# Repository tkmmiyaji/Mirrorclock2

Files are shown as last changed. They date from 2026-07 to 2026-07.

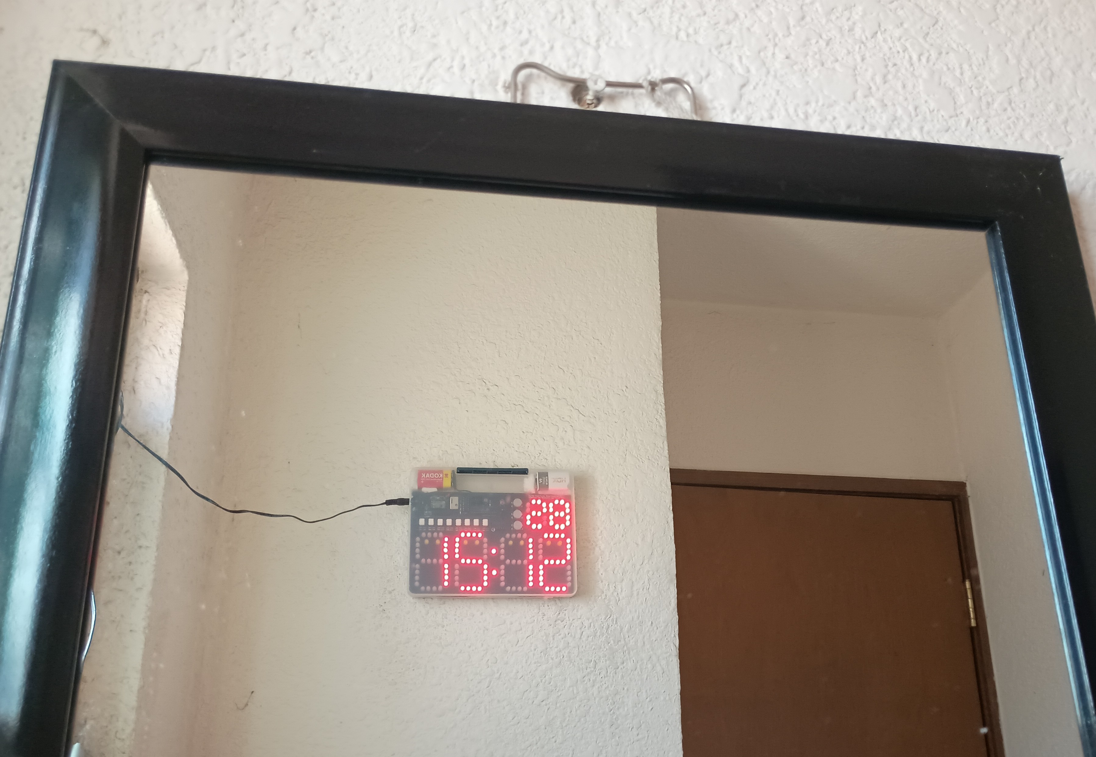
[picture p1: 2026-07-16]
Gallery/Through_the_Looking-Glass.jpg

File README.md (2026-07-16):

# Mirrorclock2 --- Through the Looking Glass and How the Digital Clock Looks
# 鏡の国のデジタル時計  Ver. 2.2 b 

### by Homebrew and Electronics Lab Cosmic Web, 16 Jul, 2026

## Summary
This repository contains the hardware designs (KiCAD) and the software (AVR assembly language). The hardware design and software are distributed with the Beerware license. See LICENSE.md  

## Hardware

The KiCAD Ver. 10 project files (incl.  kicad_pro, kicad_pcb, and kicad_sch files are included with necessary ./KiCAD.

* AVR: The 28-dip pachage of the Atmega48,88,168,328 and variants should work. 
* The resistor footprints on the PCB accept either THT (3 DIP pitches/7.62mm between holes) or SMD (1206) components. The LED footprints accept 3mm, 5mm diameter ones that have one DIP pitch (2.54mm) between leads. You may be able to place SMD LEDs if you dare.
* Place the tilt switch diagonally, so that the display is stably in the normal mode (see below) when it is placed on a level surface. See ./Gallery/Tilt_Switch_small.jpg.

### Hard-to-find components

* The temperature-compensated Crytsal Module Kyocera KTXO-18 (12.8MHz) or Mercury VCTCXO VM39S5G is used. The latter can be purchased at Akizuki Denshi Tsuusho in Akihabara, Tokyo (https://akizukidenshi.com/catalog/g/g107275/) (availbale as of July, 2026). There may be easier-to find equivalent SMD parts, but to use these a modification in the PCB footprint is required.  

## Software AVRClock2

This software is written in the assmbly language and can be compiled with avra (https://github.com/Ro5bert/avra) and uploaded to the chip using avrdude (https://github.com/avrdudes/avrdude/), both included in the standard repositories of many Linux distros.

### How to Compile/Install (Linux)
* Install avrdude and avra to your system.
* Connect an ISP programmer to the ISP header (6-pin) on board. Watch the orientation. Match the ISP connector bump to that of the PCB drawing.
* Go to directory: ./AVRA
* Open Makefile in your editor and edit the lines with "MCU_TARGET =" and "PROGRAMMER =" to your chip and programmer respectively. Check the port where the programmer is connected and adjust the PORT=/dev/ttyUSB0 line if needed.
* Also the LED brightness auto-adjustment parameters can be set by editing "FA_LIM =" and "BR_LIM =" lines. See Makefile comments for more explanations. 
* From the shell: <br>
SHELL>make                # This compiles the program. <br>
SHELL>make install        # This installs (uploads) the binary to the chip. <br>

## Usage Instructions 
* Connect an external 12V power source.
* It is highly recommended to connect a 9V rectangular battery (called 006P in Japan) for time backup.
* When the unit turns on or reset with the RST button, the clock displays 00:00 00. The clock starts running.
* __Time Adjustment:__ There are three buttons aligned vertically. With a long (~2 sec) push of the central button (MODE), the system enters the hour adjustment mode. Dots in the hour zone blink. You can adjust hours by pushing the upper (ADJ_FWD) and/or lower (ADJ_BWD) buttons. One more pressing of the central button leads to the minute adjustment mode. Dots in the minute zone blink. Use the ADJ_FWD and/or ADJ_BWD buttons to adjust the minute. Note that a long push **will not** make the forward/backward move fast. Whenever the minute is changed, the second zone is reset to zero. When you want to adjust the clock to a second level, push the ADJ_FWD/ADJ_BWD button at the exact moment the reference clock ticks a zero second.
* One more push of the MODE will return the clock to the normal mode.
* __LED Check:__ In the normal mode, pressing the upper button will turn on all the LEDs.
* LED brightness changes responding to the ambient brightness. A press of the lower button shows some calibration and brightness information. There is a trimpot for limited adjustments of the ambient-to-LED brightness relation. Wider range of adjustment is possible in the software (See above).
* __Normal Mode:__ When the clock is right-side up or on a level surface (i.e. the HH:MM display is above the circuts), it displays the clock normally.
* __Mirror Mode: Turn the clock upside down and look through a mirror!__ The roles of ADJ_FWD and ADJ_BWD buttons are also exchanged in the time adjustment.

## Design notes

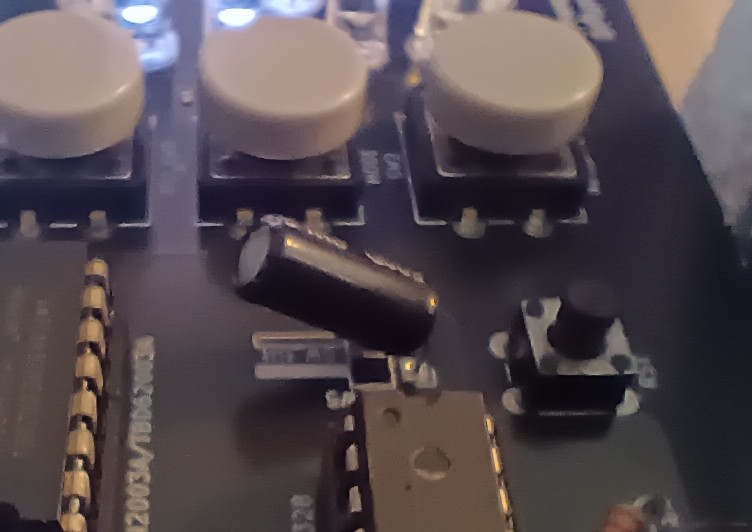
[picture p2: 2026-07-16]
Gallery/Tilt_Switch_small.jpg

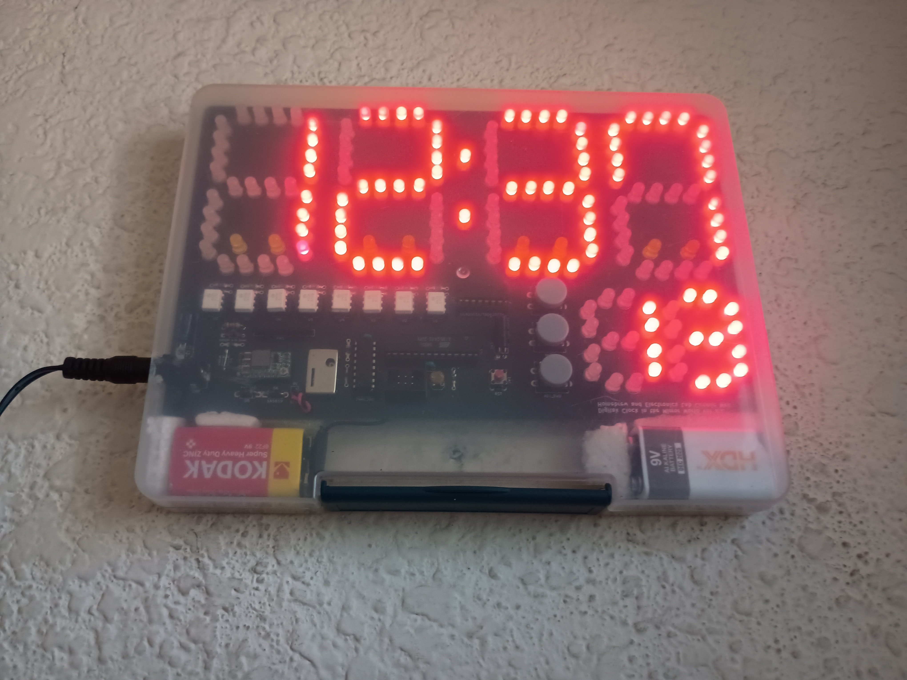
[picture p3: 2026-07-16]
Gallery/NormalMode.jpg

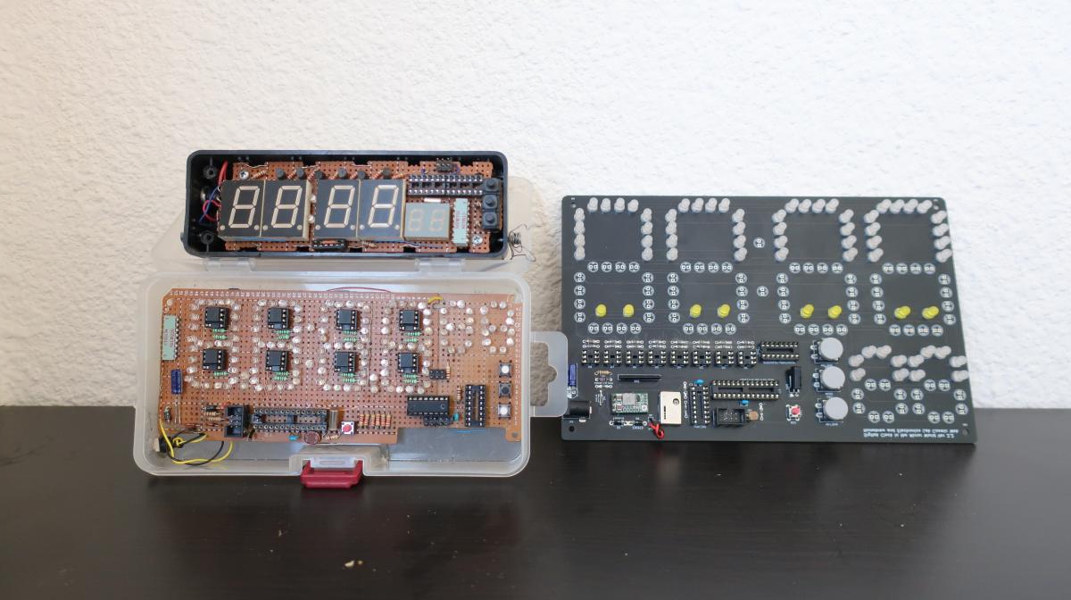
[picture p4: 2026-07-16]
Gallery/MirrorClock_Generations_small.jpg

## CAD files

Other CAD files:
AVRA/AVRClock2.obj

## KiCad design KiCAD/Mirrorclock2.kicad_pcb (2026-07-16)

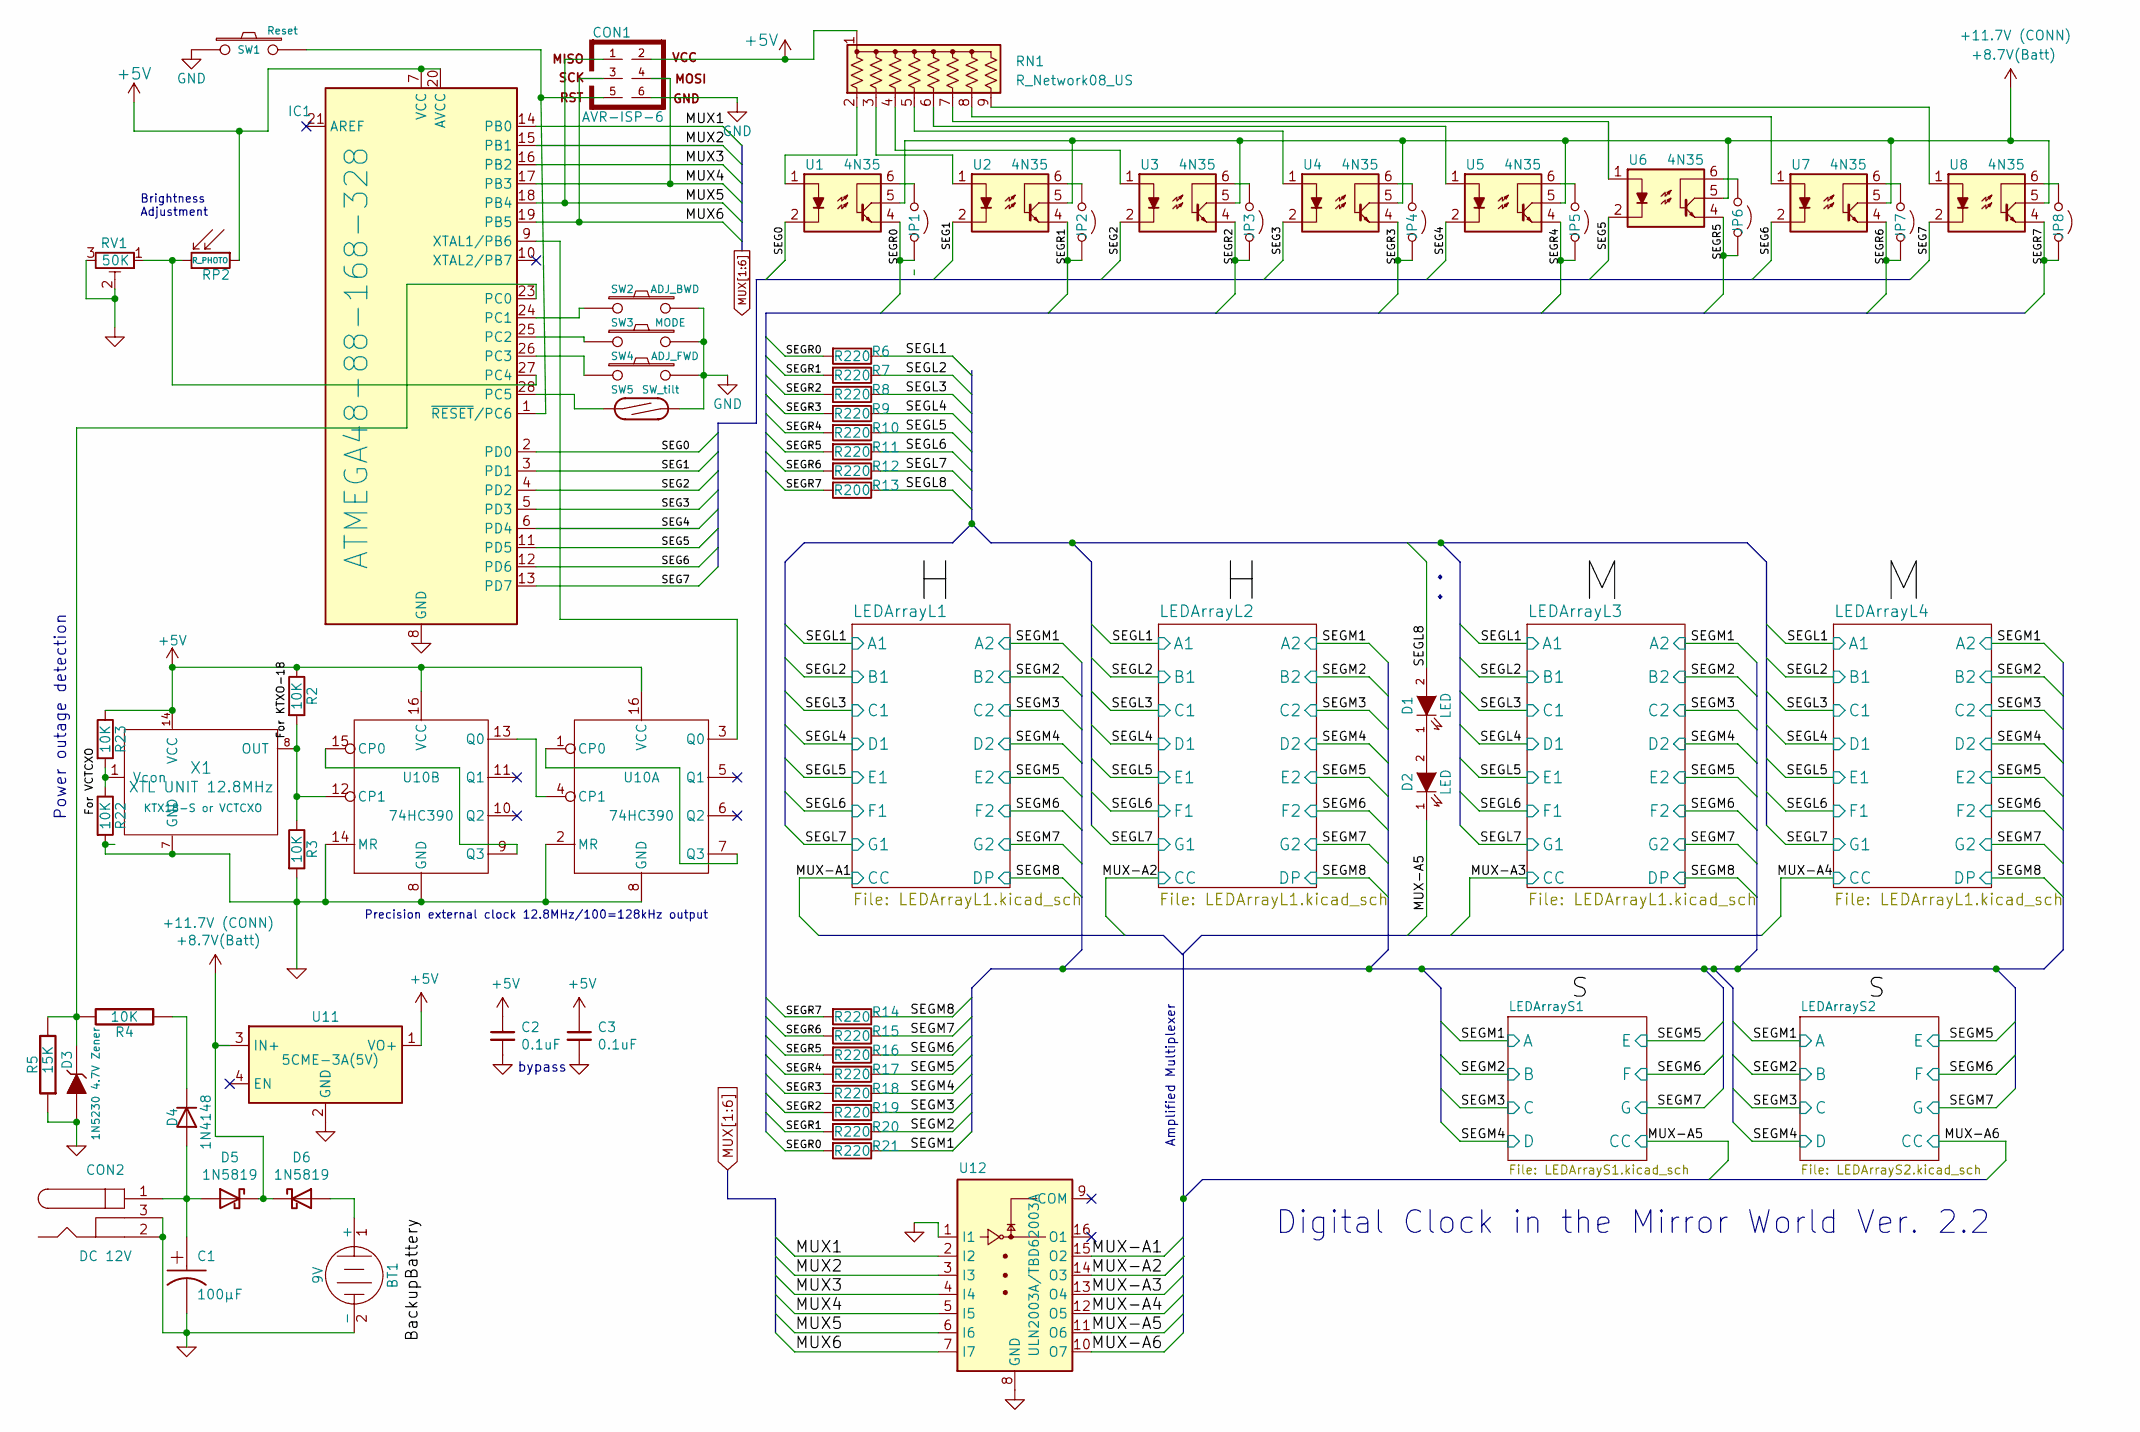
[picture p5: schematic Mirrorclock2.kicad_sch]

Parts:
BT1: 9V; PinHeader_1x02_P2.54mm_Vertical
C1: 100μF; CP_Radial_D6.3mm_P2.50mm
C2, C3: 0.1uF; C_Disc_D3.4mm_W2.1mm_P2.50mm
CON1: AVR-ISP-6; AVRISP-6P
CON2: DC 12V; BarrelJack_Horizontal
D1, D2: LED; LED_MULTI
D3: 1N5230 4.7V Zener; D_DO-34_SOD68_P7.62mm_Horizontal
D4: 1N4148; D_DO-35_SOD27_P7.62mm_Horizontal
D5, D6: 1N5819; D_DO-41_SOD81_P7.62mm_Horizontal
IC1: ATMEGA48-88-168-328; DIP-28_W7.62mm
JP1, JP2, JP3, JP4, JP5, JP6, JP7, JP8: Jumper_2_Open; SolderJumper-2_P1.3mm_Open_RoundedPad1.0x1.5mm
R2, R3, R4, R22, R23: 10K; R_THT_SMD1206
R5: 15K; R_THT_SMD1206
R6, R7, R8, R9, R10, R11, R12, R14, R15, R16, R17, R18, R19, R20, R21: R220; R_THT_SMD1206
R13: R200; R_THT_SMD1206
RN1: R_Network08_US; R_Array_SIP9
RP2: R_PHOTO; R_LDR_5.1x4.3mm_P3.4mm_Vertical
RV1: 50K; Potentiometer_Runtron_RM-065_Vertical
SW1: Reset; SW_PUSH_6mm
SW2: ADJ_BWD; SW_PUSH-12mm_Wuerth-430476085716
SW3: MODE; SW_PUSH-12mm_Wuerth-430476085716
SW4: ADJ_FWD; SW_PUSH-12mm_Wuerth-430476085716
SW5: SW_tilt; Sw_tilt_holes
U1, U2, U3, U4, U5, U6, U7, U8: 4N35; DIP-6_W7.62mm
U10: 74HC390; DIP-16_W7.62mm
U11: 5CME-3A(5V); DCDC-Module-Drok
U12: ULN2003A/TBD62003A; DIP-16_W7.62mm
X1: XTL UNIT 12.8MHz; Crystal_M39S_KTXO18; Part KTX18-S or VCTCXO

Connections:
+5V: C2.1, C3.1, CON1.2, IC1.7 (VCC), IC1.20 (AVCC), R2.1, R23.1, RN1.1 (common), RP2.1, U10.16 (VCC), U11.1 (VO+), X1.14 (VCC)
+12V: D5.1 (K), D6.1 (K), U1.5, U2.5, U3.5, U4.5, U5.5, U6.5, U7.5, U8.5, U11.3 (IN+)
/MUX1: IC1.14 (PB0), U12.2 (I2)
/MUX2: IC1.15 (PB1), U12.3 (I3)
/MUX3: IC1.16 (PB2), U12.4 (I4)
/MUX4: CON1.4, IC1.17 (PB3), U12.5 (I5)
/MUX5: CON1.1, IC1.18 (PB4), U12.6 (I6)
/MUX6: CON1.3, IC1.19 (PB5), U12.7 (I7)
/MUX-A1: U12.15 (O2); also elsewhere on the board
/MUX-A2: U12.14 (O3); also elsewhere on the board
/MUX-A3: U12.13 (O4); also elsewhere on the board
/MUX-A4: U12.12 (O5); also elsewhere on the board
/MUX-A5: D2.1 (K), U12.11 (O6); also elsewhere on the board
/MUX-A6: U12.10 (O7); also elsewhere on the board
/SEG0: IC1.2 (PD0), U1.2
/SEG1: IC1.3 (PD1), U2.2
/SEG2: IC1.4 (PD2), U3.2
/SEG3: IC1.5 (PD3), U4.2
/SEG4: IC1.6 (PD4), U5.2
/SEG5: IC1.11 (PD5), U6.2
/SEG6: IC1.12 (PD6), U7.2
/SEG7: IC1.13 (PD7), U8.2
/SEGL1: R6.1; also elsewhere on the board
/SEGL2: R7.1; also elsewhere on the board
/SEGL3: R8.1; also elsewhere on the board
/SEGL4: R9.1; also elsewhere on the board
/SEGL5: R10.1; also elsewhere on the board
/SEGL6: R11.1; also elsewhere on the board
/SEGL7: R12.1; also elsewhere on the board
/SEGL8: D1.2 (A), R13.1
/SEGM1: R21.1; also elsewhere on the board
/SEGM2: R20.1; also elsewhere on the board
/SEGM3: R19.1; also elsewhere on the board
/SEGM4: R18.1; also elsewhere on the board
/SEGM5: R17.1; also elsewhere on the board
/SEGM6: R16.1; also elsewhere on the board
/SEGM7: R15.1; also elsewhere on the board
/SEGM8: R14.1; also elsewhere on the board
/SEGR0: JP1.2 (B), R6.2, R21.2, U1.4
/SEGR1: JP2.2 (B), R7.2, R20.2, U2.4
/SEGR2: JP3.2 (B), R8.2, R19.2, U3.4
/SEGR3: JP4.2 (B), R9.2, R18.2, U4.4
/SEGR4: JP5.2 (B), R10.2, R17.2, U5.4
/SEGR5: JP6.2 (B), R11.2, R16.2, U6.4
/SEGR6: JP7.2 (B), R12.2, R15.2, U7.4
/SEGR7: JP8.2 (B), R13.2, R14.2, U8.4
GND: BT1.2 (-), C1.2, C2.2, C3.2, CON1.6, CON2.2, CON2.3, D3.2 (A), IC1.8 (GND), IC1.22 (GND), R3.2, R5.1, R22.2, RV1.2, RV1.3, SW1.1, SW2.2, SW3.2, SW4.2, SW5.2, U10.2 (MR), U10.8 (GND), U10.14 (MR), U11.2 (GND), U12.1 (I1), U12.8 (GND), X1.7 (GND)
unnamed: BT1.1 (+), D6.2 (A)
unnamed: D1.1 (K), D2.2 (A)
unnamed: D3.1 (K), IC1.23 (PC0), R4.2, R5.2
unnamed: C1.1, CON2.1, D4.2 (A), D5.2 (A)
unnamed: D4.1 (K), R4.1
unnamed: IC1.24 (PC1), SW2.1
unnamed: IC1.25 (PC2), SW3.1
unnamed: IC1.26 (PC3), SW4.1
unnamed: IC1.9 (XTAL1/PB6), U10.3 (Q0)
unnamed: CON1.5, IC1.1 (~RESET/PC6), SW1.2
unnamed: JP1.1 (A), U1.6
unnamed: JP2.1 (A), U2.6
unnamed: JP3.1 (A), U3.6
unnamed: JP4.1 (A), U4.6
unnamed: JP5.1 (A), U5.6
unnamed: JP6.1 (A), U6.6
unnamed: JP7.1 (A), U7.6
unnamed: JP8.1 (A), U8.6
unnamed: RN1.2 (R1), U1.1
unnamed: RN1.3 (R2), U2.1
unnamed: RN1.4 (R3), U3.1
unnamed: RN1.5 (R4), U4.1
unnamed: RN1.6 (R5), U5.1
unnamed: RN1.7 (R6), U6.1
unnamed: RN1.8 (R7), U7.1
unnamed: RN1.9 (R8), U8.1
unnamed: U10.1 (CP0), U10.7 (Q3)
unnamed: U10.4 (CP1), U10.13 (Q0)
unnamed: U10.9 (Q3), U10.15 (CP0)
unnamed: R2.2, R3.1, U10.12 (CP1), X1.8 (OUT)
unnamed: R22.1, R23.2, X1.1 (Vcon)

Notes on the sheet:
Digital Clock in the Mirror World Ver. 2.2
Precision external clock 12.8MHz/100=128kHz output
Brightness Adjustment
Amplified Multiplexer
bypass
Power outage detection

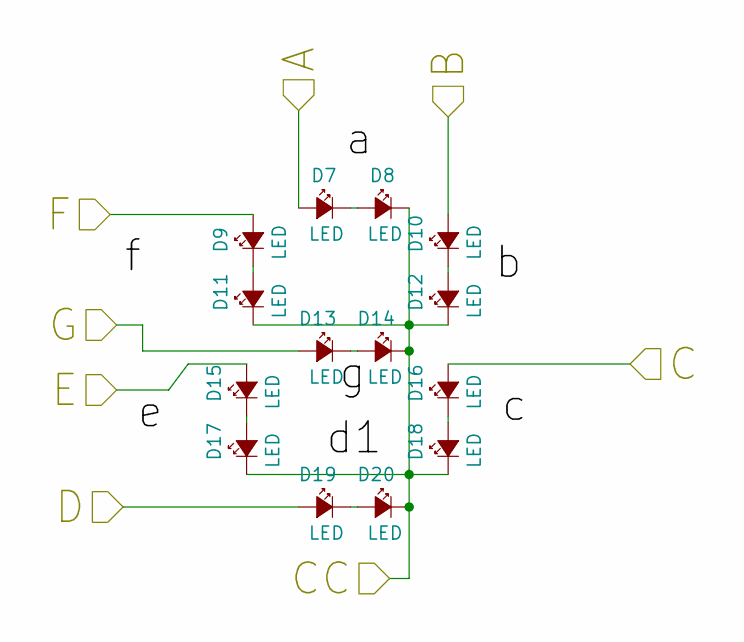
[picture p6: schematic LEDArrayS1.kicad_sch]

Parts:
D7, D8, D9, D10, D11, D12, D13, D14, D15, D16, D17, D18, D19, D20: LED; LED_MULTI

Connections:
/MUX-A5: D8.1 (K), D11.1 (K), D12.1 (K), D14.1 (K), D17.1 (K), D18.1 (K), D20.1 (K); also elsewhere on the board
/SEGM1: D7.2 (A); also elsewhere on the board
/SEGM2: D10.2 (A); also elsewhere on the board
/SEGM3: D16.2 (A); also elsewhere on the board
/SEGM4: D19.2 (A); also elsewhere on the board
/SEGM5: D15.2 (A); also elsewhere on the board
/SEGM6: D9.2 (A); also elsewhere on the board
/SEGM7: D13.2 (A); also elsewhere on the board
unnamed: D7.1 (K), D8.2 (A)
unnamed: D10.1 (K), D12.2 (A)
unnamed: D9.1 (K), D11.2 (A)
unnamed: D13.1 (K), D14.2 (A)
unnamed: D15.1 (K), D17.2 (A)
unnamed: D16.1 (K), D18.2 (A)
unnamed: D19.1 (K), D20.2 (A)

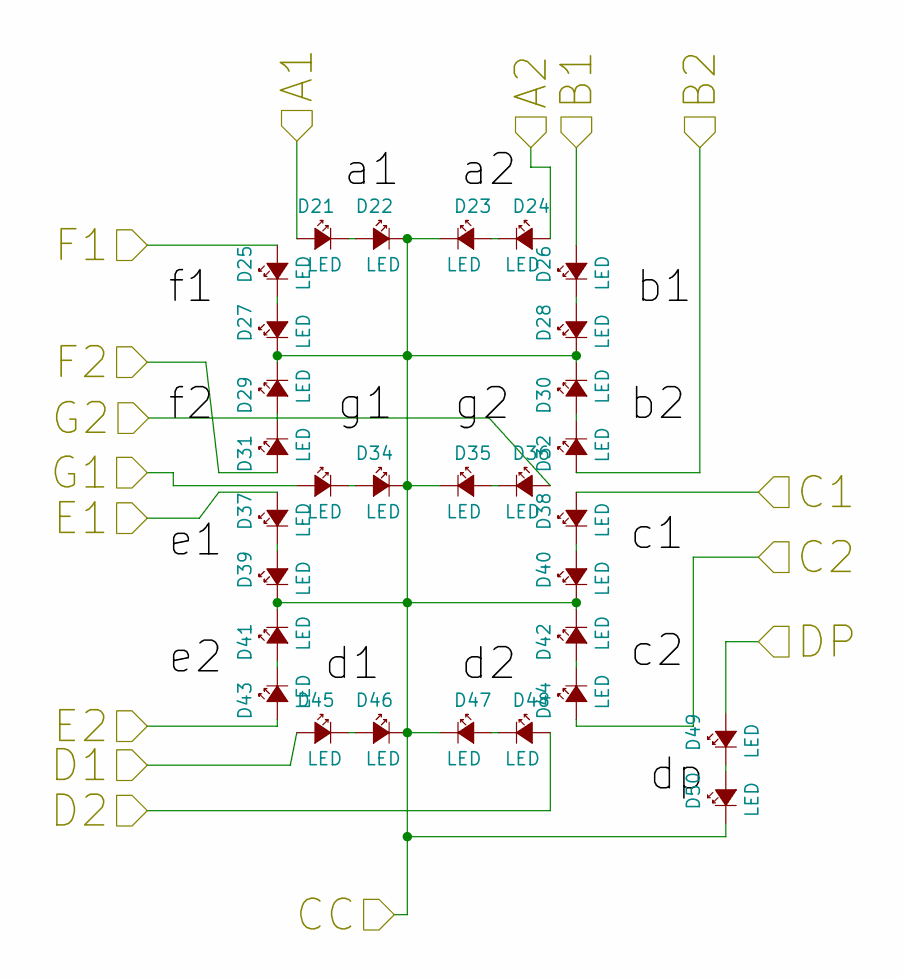
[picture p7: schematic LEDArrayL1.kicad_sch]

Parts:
D21, D22, D23, D24, D25, D26, D27, D28, D29, D30, D31, D32, D33, D34, D35, D36, D37, D38, D39, D40, D41, D42, D43, D44, D45, D46, D47, D48: LED; LED_MULTI
D49, D50: LED; LED_MULTI_SIMPLE

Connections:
/MUX-A1: D22.1 (K), D23.1 (K), D27.1 (K), D28.1 (K), D29.1 (K), D30.1 (K), D34.1 (K), D35.1 (K), D39.1 (K), D40.1 (K), D41.1 (K), D42.1 (K), D46.1 (K), D47.1 (K), D50.1 (K); also elsewhere on the board
/SEGL1: D21.2 (A); also elsewhere on the board
/SEGL2: D26.2 (A); also elsewhere on the board
/SEGL3: D38.2 (A); also elsewhere on the board
/SEGL4: D45.2 (A); also elsewhere on the board
/SEGL5: D37.2 (A); also elsewhere on the board
/SEGL6: D25.2 (A); also elsewhere on the board
/SEGL7: D33.2 (A); also elsewhere on the board
/SEGM1: D24.2 (A); also elsewhere on the board
/SEGM2: D32.2 (A); also elsewhere on the board
/SEGM3: D44.2 (A); also elsewhere on the board
/SEGM4: D48.2 (A); also elsewhere on the board
/SEGM5: D43.2 (A); also elsewhere on the board
/SEGM6: D31.2 (A); also elsewhere on the board
/SEGM7: D36.2 (A); also elsewhere on the board
/SEGM8: D49.2 (A); also elsewhere on the board
unnamed: D21.1 (K), D22.2 (A)
unnamed: D23.2 (A), D24.1 (K)
unnamed: D25.1 (K), D27.2 (A)
unnamed: D26.1 (K), D28.2 (A)
unnamed: D29.2 (A), D31.1 (K)
unnamed: D30.2 (A), D32.1 (K)
unnamed: D33.1 (K), D34.2 (A)
unnamed: D35.2 (A), D36.1 (K)
unnamed: D37.1 (K), D39.2 (A)
unnamed: D38.1 (K), D40.2 (A)
unnamed: D41.2 (A), D43.1 (K)
unnamed: D42.2 (A), D44.1 (K)
unnamed: D45.1 (K), D46.2 (A)
unnamed: D47.2 (A), D48.1 (K)
unnamed: D49.1 (K), D50.2 (A)

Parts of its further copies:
D51, D52, D53, D54, D55, D56, D57, D58, D59, D60, D61, D62, D63, D64, D65, D66, D67, D68, D69, D70, D71, D72, D73, D74, D75, D76, D77, D78, D81, D82, D83, D84, D85, D86, D87, D88, D89, D90, D91, D92, D93, D94, D95, D96, D97, D98, D99, D100, D101, D102, D103, D104, D105, D106, D107, D108, D111, D112, D113, D114, D115, D116, D117, D118, D119, D120, D121, D122, D123, D124, D125, D126, D127, D128, D129, D130, D131, D132, D133, D134, D135, D136, D137, D138: LED; LED_MULTI
D79, D80, D109, D110, D139, D140: LED; LED_MULTI_SIMPLE

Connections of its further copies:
/MUX-A2: D52.1 (K), D53.1 (K), D57.1 (K), D58.1 (K), D59.1 (K), D60.1 (K), D64.1 (K), D65.1 (K), D69.1 (K), D70.1 (K), D71.1 (K), D72.1 (K), D76.1 (K), D77.1 (K), D80.1 (K); also elsewhere on the board
/MUX-A3: D82.1 (K), D83.1 (K), D87.1 (K), D88.1 (K), D89.1 (K), D90.1 (K), D94.1 (K), D95.1 (K), D99.1 (K), D100.1 (K), D101.1 (K), D102.1 (K), D106.1 (K), D107.1 (K), D110.1 (K); also elsewhere on the board
/MUX-A4: D112.1 (K), D113.1 (K), D117.1 (K), D118.1 (K), D119.1 (K), D120.1 (K), D124.1 (K), D125.1 (K), D129.1 (K), D130.1 (K), D131.1 (K), D132.1 (K), D136.1 (K), D137.1 (K), D140.1 (K); also elsewhere on the board
/SEGL1: D51.2 (A), D81.2 (A), D111.2 (A); also elsewhere on the board
/SEGL2: D56.2 (A), D86.2 (A), D116.2 (A); also elsewhere on the board
/SEGL3: D68.2 (A), D98.2 (A), D128.2 (A); also elsewhere on the board
/SEGL4: D75.2 (A), D105.2 (A), D135.2 (A); also elsewhere on the board
/SEGL5: D67.2 (A), D97.2 (A), D127.2 (A); also elsewhere on the board
/SEGL6: D55.2 (A), D85.2 (A), D115.2 (A); also elsewhere on the board
/SEGL7: D63.2 (A), D93.2 (A), D123.2 (A); also elsewhere on the board
/SEGM1: D54.2 (A), D84.2 (A), D114.2 (A); also elsewhere on the board
/SEGM2: D62.2 (A), D92.2 (A), D122.2 (A); also elsewhere on the board
/SEGM3: D74.2 (A), D104.2 (A), D134.2 (A); also elsewhere on the board
/SEGM4: D78.2 (A), D108.2 (A), D138.2 (A); also elsewhere on the board
/SEGM5: D73.2 (A), D103.2 (A), D133.2 (A); also elsewhere on the board
/SEGM6: D61.2 (A), D91.2 (A), D121.2 (A); also elsewhere on the board
/SEGM7: D66.2 (A), D96.2 (A), D126.2 (A); also elsewhere on the board
/SEGM8: D79.2 (A), D109.2 (A), D139.2 (A); also elsewhere on the board
unnamed: D51.1 (K), D52.2 (A)
unnamed: D53.2 (A), D54.1 (K)
unnamed: D55.1 (K), D57.2 (A)
unnamed: D56.1 (K), D58.2 (A)
unnamed: D59.2 (A), D61.1 (K)
unnamed: D60.2 (A), D62.1 (K)
unnamed: D63.1 (K), D64.2 (A)
unnamed: D65.2 (A), D66.1 (K)
unnamed: D67.1 (K), D69.2 (A)
unnamed: D68.1 (K), D70.2 (A)
unnamed: D71.2 (A), D73.1 (K)
unnamed: D72.2 (A), D74.1 (K)
unnamed: D75.1 (K), D76.2 (A)
unnamed: D77.2 (A), D78.1 (K)
unnamed: D79.1 (K), D80.2 (A)
unnamed: D81.1 (K), D82.2 (A)
unnamed: D83.2 (A), D84.1 (K)
unnamed: D85.1 (K), D87.2 (A)
unnamed: D86.1 (K), D88.2 (A)
unnamed: D89.2 (A), D91.1 (K)
unnamed: D90.2 (A), D92.1 (K)
unnamed: D93.1 (K), D94.2 (A)
unnamed: D95.2 (A), D96.1 (K)
unnamed: D97.1 (K), D99.2 (A)
unnamed: D98.1 (K), D100.2 (A)
unnamed: D101.2 (A), D103.1 (K)
unnamed: D102.2 (A), D104.1 (K)
unnamed: D105.1 (K), D106.2 (A)
unnamed: D107.2 (A), D108.1 (K)
unnamed: D109.1 (K), D110.2 (A)
unnamed: D111.1 (K), D112.2 (A)
unnamed: D113.2 (A), D114.1 (K)
unnamed: D115.1 (K), D117.2 (A)
unnamed: D116.1 (K), D118.2 (A)
unnamed: D119.2 (A), D121.1 (K)
unnamed: D120.2 (A), D122.1 (K)
unnamed: D123.1 (K), D124.2 (A)
unnamed: D125.2 (A), D126.1 (K)
unnamed: D127.1 (K), D129.2 (A)
unnamed: D128.1 (K), D130.2 (A)
unnamed: D131.2 (A), D133.1 (K)
unnamed: D132.2 (A), D134.1 (K)
unnamed: D135.1 (K), D136.2 (A)
unnamed: D137.2 (A), D138.1 (K)
unnamed: D139.1 (K), D140.2 (A)

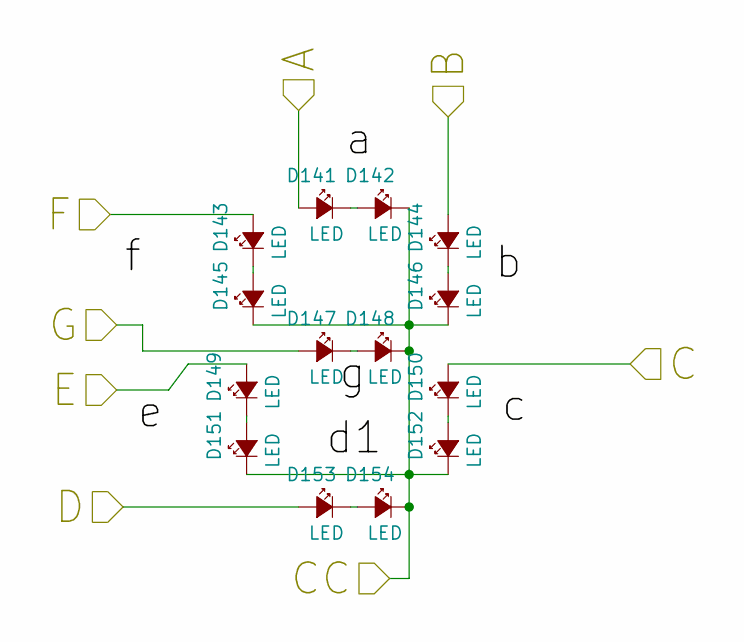
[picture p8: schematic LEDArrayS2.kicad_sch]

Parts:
D141, D142, D143, D144, D145, D146, D147, D148, D149, D150, D151, D152, D153, D154: LED; LED_MULTI

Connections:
/MUX-A6: D142.1 (K), D145.1 (K), D146.1 (K), D148.1 (K), D151.1 (K), D152.1 (K), D154.1 (K); also elsewhere on the board
/SEGM1: D141.2 (A); also elsewhere on the board
/SEGM2: D144.2 (A); also elsewhere on the board
/SEGM3: D150.2 (A); also elsewhere on the board
/SEGM4: D153.2 (A); also elsewhere on the board
/SEGM5: D149.2 (A); also elsewhere on the board
/SEGM6: D143.2 (A); also elsewhere on the board
/SEGM7: D147.2 (A); also elsewhere on the board
unnamed: D141.1 (K), D142.2 (A)
unnamed: D143.1 (K), D145.2 (A)
unnamed: D144.1 (K), D146.2 (A)
unnamed: D147.1 (K), D148.2 (A)
unnamed: D149.1 (K), D151.2 (A)
unnamed: D150.1 (K), D152.2 (A)
unnamed: D153.1 (K), D154.2 (A)

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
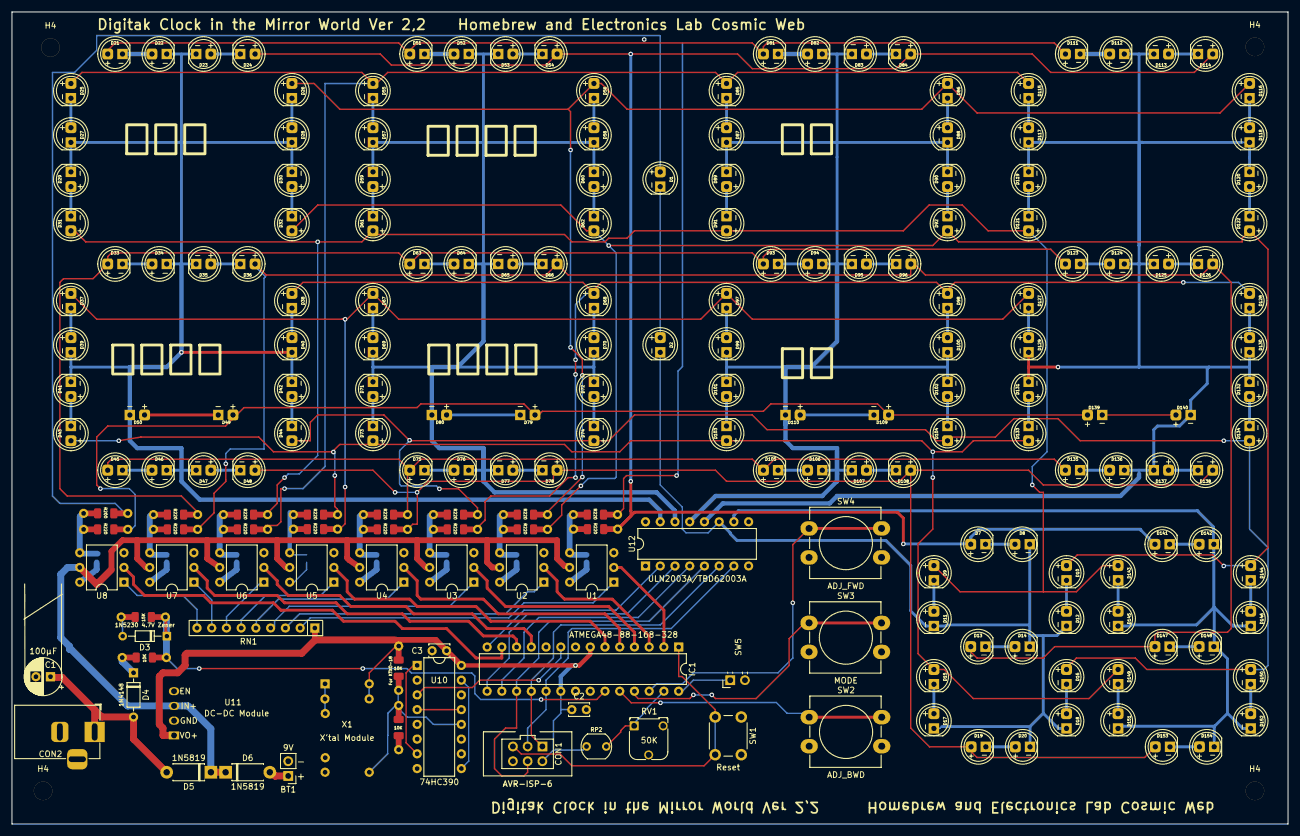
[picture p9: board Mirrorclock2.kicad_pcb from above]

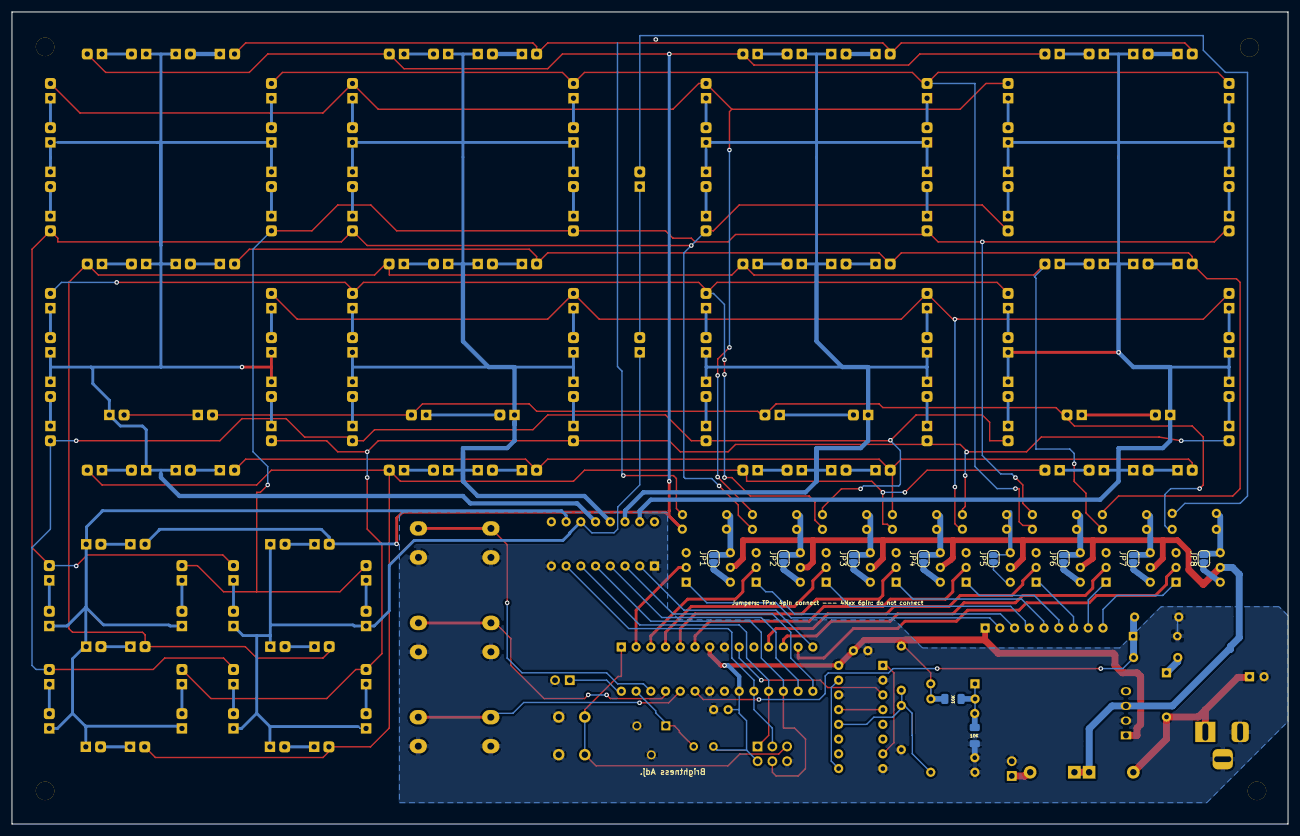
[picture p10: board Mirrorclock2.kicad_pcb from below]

Board: 2 copper layers, 220.0 x 140.0 mm, 215 parts (10 on the bottom side), 153 nets.

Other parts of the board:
H4, H4#2, H4#3, H4#4: MountingHole; MountingHole_3.2mm_M3_ISO7380

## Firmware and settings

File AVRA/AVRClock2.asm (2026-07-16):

;;;***********************************************************************
;;;*  AVR Digital Clock in the Mirror World                              *
;;;* 								         *
;;;*  File Name            :"AVRClock2.asm"                              *
;;;*  Title                :AVR Clock 2 Source                           *
;;;*  Date (Start)         :25May2022                                    *
;;;*  		                                                         *
;;;*  Version              :2.2dev (28 jun 2026)                         *
;;;*  Target MCUs          :ATmega48-88-168-328                          *
;;;*                                                                     *
;;;* DESCRIPTION                                                         *
;;;*     Ver 2.0dev  ; 5 May 2022: Start Development                     *
;;;*     Ver 2.2     ; 1 Jun 2026: For new JLCPCB Board-1/		 *
;;;*		  		    Slight pin changes        		 *
;;;***********************************************************************
		.NOLIST
		;;  Makefile replaces m88Pdef.inc to an appropriate .inc file.
		.include "m88Pdef.inc"
		;; .include "m48def.inc"
                ;; .include "m88PAdef.inc"
                ;; .include "m328def.inc"

		.LIST   
		;;	 ***** Global Register Variables
		.def    NULL 	=r14	                  ; Always 0 
		.def    SR	=r15                              ; Used for Status Register Escape
		.def    A	=r16                              ; Local use/input/output 	
		.def    B	=r17                              ; Local use
		.def    C	=r18                              ; Used for LED Brightness
		.def    D	=r19                              ; Local use
		.def    E	=r20                              ; Local use
		.def    F	=r21   	                          ; Used for Ambient brightness	
		.def    ADJ	=r22  				  ; ADJUSTMENT FLAGs 
	;;	** Use the following Registers to Store Current Hour/Packed BCD
		.def    HH	=r23
		.def    MM	=r24
		.def    SS	=r25
	;;	*** Brightness adjustment. Adjust for your system (LED, Photoresitor properties)
	;;	ADCH value is divided by 4 to sADC=0--63. LED faintest if sADC<=FA_LIM, Brightest (full duty)
	;;	if sADC>FA_LIM+BR_LIM. In general, BR_LIM<63-FA_LIM to attain full LED brightness at the bright
	;;	ambient light, but logically it accepts up to 255. LED duty cylce is approximately (sADC-FA_LIM+1)/BR_LIM
	;;	(sADC>=FA_LIM) or 1/BR_LIM (sADC<=FA_LIM).
		.equ	BR_LIM	= 50 	                          ; Bright limit,above which duty=full
		.equ	FA_LIM	= 10	                          ; Faint limit, below which duty=1
	;; Multiplexer channel definitions on PORTB
		.equ	S0	= 5	                          ; MUX Channel 6 = Sec lower digit
		.equ	S1	= 4	                          ; MUX Channel 5 = Sec highr digit
		.equ	M0	= 3	                          ; MUX Channel 4 = Min lower digit
		.equ	M1	= 2	                          ; MUX Channel 3 = Min highr digit
		.equ	H0	= 1	                          ; MUX Channel 2 = Hr  lower digit
		.equ	H1	= 0	                          ; MUX Channel 1 = Hr  highr digit
								  ; MUX Channel 0 = Not used
	;; Switch and sensor pin definitions on PINC
		.equ	PWOUT	= 0	                          ; Power Outage detetction LOW is power-out (Batt Operated)
		.equ	FWBTN	= 3	                          ; Forward button pin 
		.equ	MDBTN	= 2	                          ; Mode button pin
		.equ	BWBTN	= 1	                          ; Backward button pin
		.equ	TILT	= 5	                          ; Tilt Switch
	
		.CSEG   
                                                  ;********** 	Interupt Vector	**********
		.org    0x000
			rjmp    RESET		                  ;Reset Handle
		.org    INT0addr                             ;=$001	External Interrupt0
			reti    
		.org    INT1addr                             ;=$002	External Interrupt1
			reti    
		.org    PCI0addr                             ;=$003	Pin Change Interrupt0
			reti    
		.org    PCI1addr                             ;=$004	Pin Change Interrupt1
			reti    
		.org    PCI2addr                             ;=$005	Pin Change Interrupt2
			reti    
		.org    WDTaddr	                             ;=$006	Watchdog Timeout
			reti
		.org    OC2Aaddr                             ;=$007	Timer/Counter2 Compare Match Interrupt
			rjmp    ADV_SEC	 	                  ; Timer 2 Overflow every second
		.org    OC2Baddr                             ;=$008	Timer/Counter2 Compare Match Interrupt	
			reti    
		.org    OVF2addr                             ;=$009	Overflow2 Interrupt
			reti    
		.org    ICP1addr                             ;=$00a	Input Capture1 Interrupt 	
			reti    
		.org    OC1Aaddr                             ;=$00b	Output Compare1A Interrupt 
			reti    
		.org    OC1Baddr                             ;=$00c	Output Compare1B Interrupt 
			reti    
		.org    OVF1addr                             ;=$00d	Overflow1 Interrupt 
			reti    
		.org    OC0Aaddr                             ;=$00e	Timer/Counter0 Compare Match Interrupt
			reti    
		.org    OC0Baddr                             ;=$00f	Timer/Counter0 Compare Match Interrupt	
			reti    
		.org    OVF0addr                             ;=$010	Overflow0 Interrupt
			reti    
		.org    SPIaddr                              ;=$011	SPI Interrupt 	
			reti    
		.org    URXCaddr                             ;=$012	USART Receive Complete Interrupt 
			reti    
		.org    UDREaddr                             ;=$013	USART Data Register Empty Interrupt 
			reti    
		.org    UTXCaddr                             ;=$014	USART Transmit Complete Interrupt 
			reti    
		.org    ADCCaddr                             ;=$015	ADC Conversion Complete Handle
			reti
			;;rjmp    SET_BRIGHT
		.org    ERDYaddr                             ;=$016	EEPROM write complete
			reti    
		.org    ACIaddr	                          ;=$017	Analog Comparator Interrupt 
			reti    
		.org    TWIaddr                              ;=$018	TWI Interrupt Vector Address
			reti    
		.org    SPMRaddr                             ;=$019	Store Program Memory Ready Interrupt 
			reti    
     ;;;
     ;;;	**********		Main Program Starts Here  ********
     ;;
;
RESET:
		cli					  ; Global Interupt disable	
		clr     NULL
		ldi     A,	low(RAMEND)		  ; Load low byte address of end of RAM 
		out     SPL,	A		          ; Initialize stack pointer to end of internal RAM
		ldi     A,	high(RAMEND)		  ; Load high byte address of end of RAM 
		out     SPH, 	A			  ; Initialize high byte 
;;;
;;; Setting Modes
;;; 
		;; Shut Down Unnecessary Modules for power reduction
		ldi	A,	(1<<PRUSART0)		; keep SPI/UART and ADC is on
		sts	PRR,	A
		;;	Main Clock 8MHz Internal Oscillator by Fuse Bit Setting
		;;	No pre-scaler. Operate at 8MHz, to avoid looking flickerd with dimmness control. 
		;;	External 128 kHz (12.8Mz Crystal reduce freq by 100 using 74HC390)  			
		;;	First CLKPR7=CLKPCE is enabled with all other bits 0
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
